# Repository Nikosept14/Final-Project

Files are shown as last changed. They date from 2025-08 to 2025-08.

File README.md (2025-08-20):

# 🤖 Humanoid Dancing Robot – 29 DOF Controller

This repository contains the source code and documentation for my undergraduate thesis:  
**"Rancang Bangun Sistem Kontroler 29-DOF pada Robot Penari Humanoid untuk Gerakan Tari yang Dinamis"**

---

## 📌 Project Description
This project focuses on the design and implementation of a **29 Degrees of Freedom (DOF) humanoid dancing robot**.  
The system utilizes an **ESP32 microcontroller** and **Dynamixel servomotors** to perform **dynamic dance movements**, following the guidelines of the **Indonesian Robot Contest (KRI) 2024**.  

The controller system is capable of:
- Coordinating **multi-DOF motion** for humanoid dance movements.
- Achieving flexibility and balance
- Executing pre-programmed dynamic dance sequences.

---

## 🛠️ Tech Stack
- **Hardware**: ESP32, Dynamixel Servomotors  
- **Software/Frameworks**: Arduino IDE / PlatformIO, C/C++  
- **Control Algorithm**: Multi-DOF Motion Control  
- **Reference**: KRI 2024 Dance Robot Guidelines

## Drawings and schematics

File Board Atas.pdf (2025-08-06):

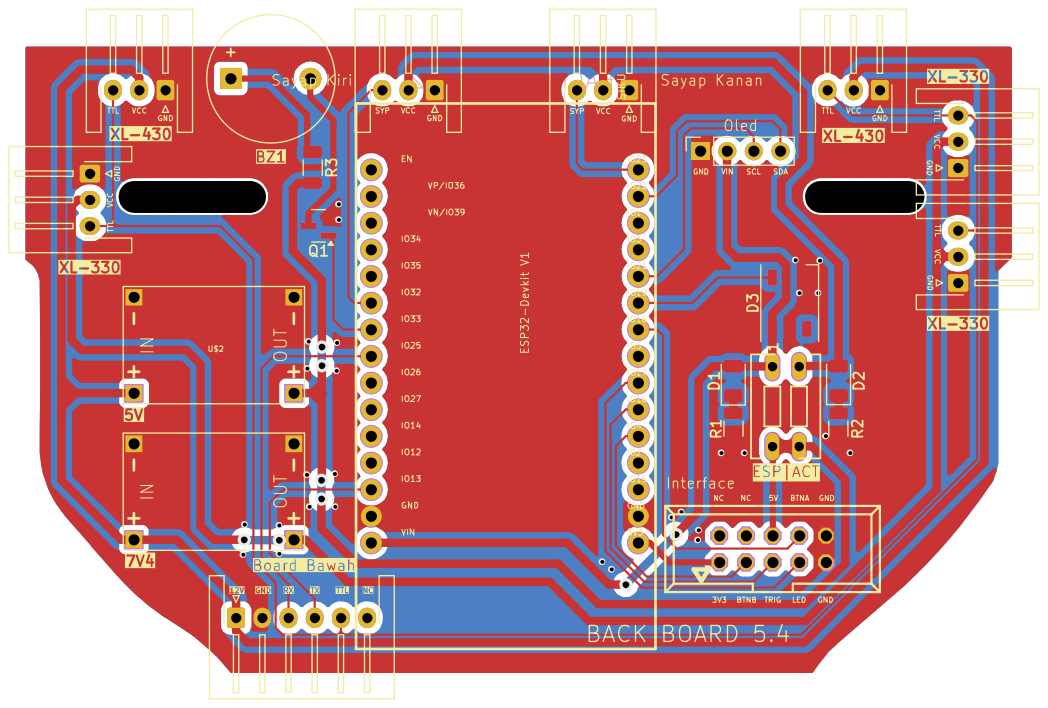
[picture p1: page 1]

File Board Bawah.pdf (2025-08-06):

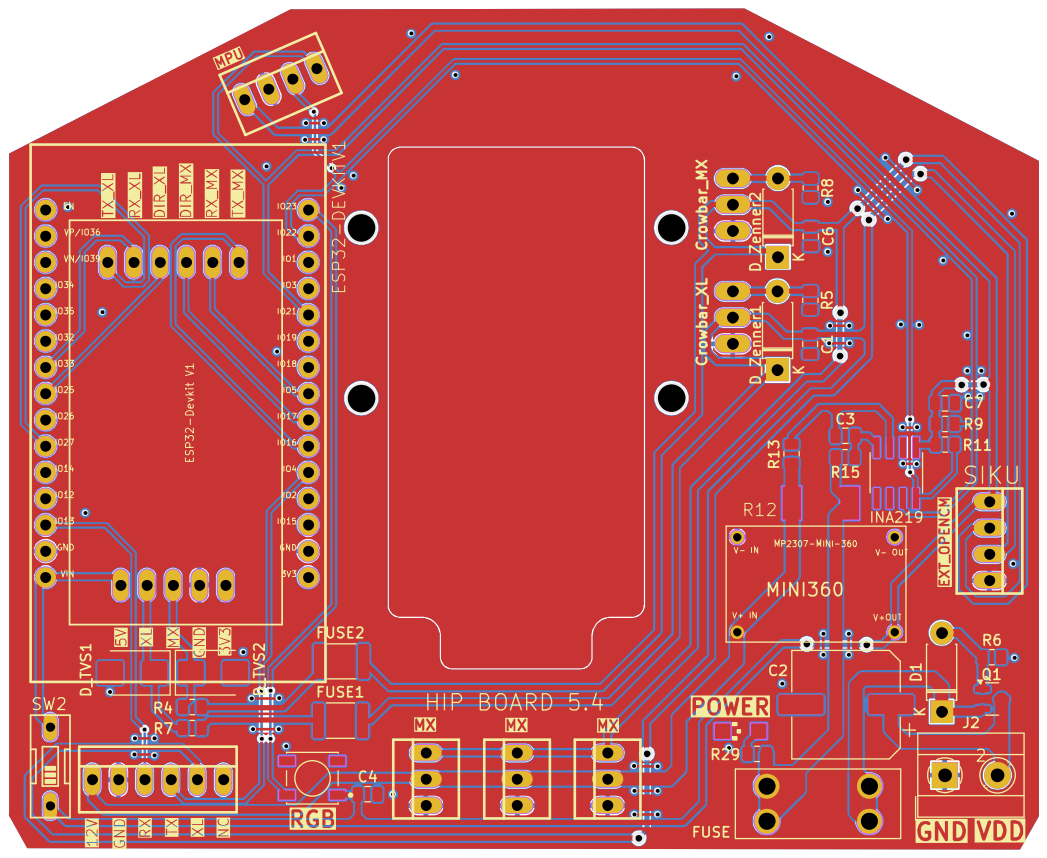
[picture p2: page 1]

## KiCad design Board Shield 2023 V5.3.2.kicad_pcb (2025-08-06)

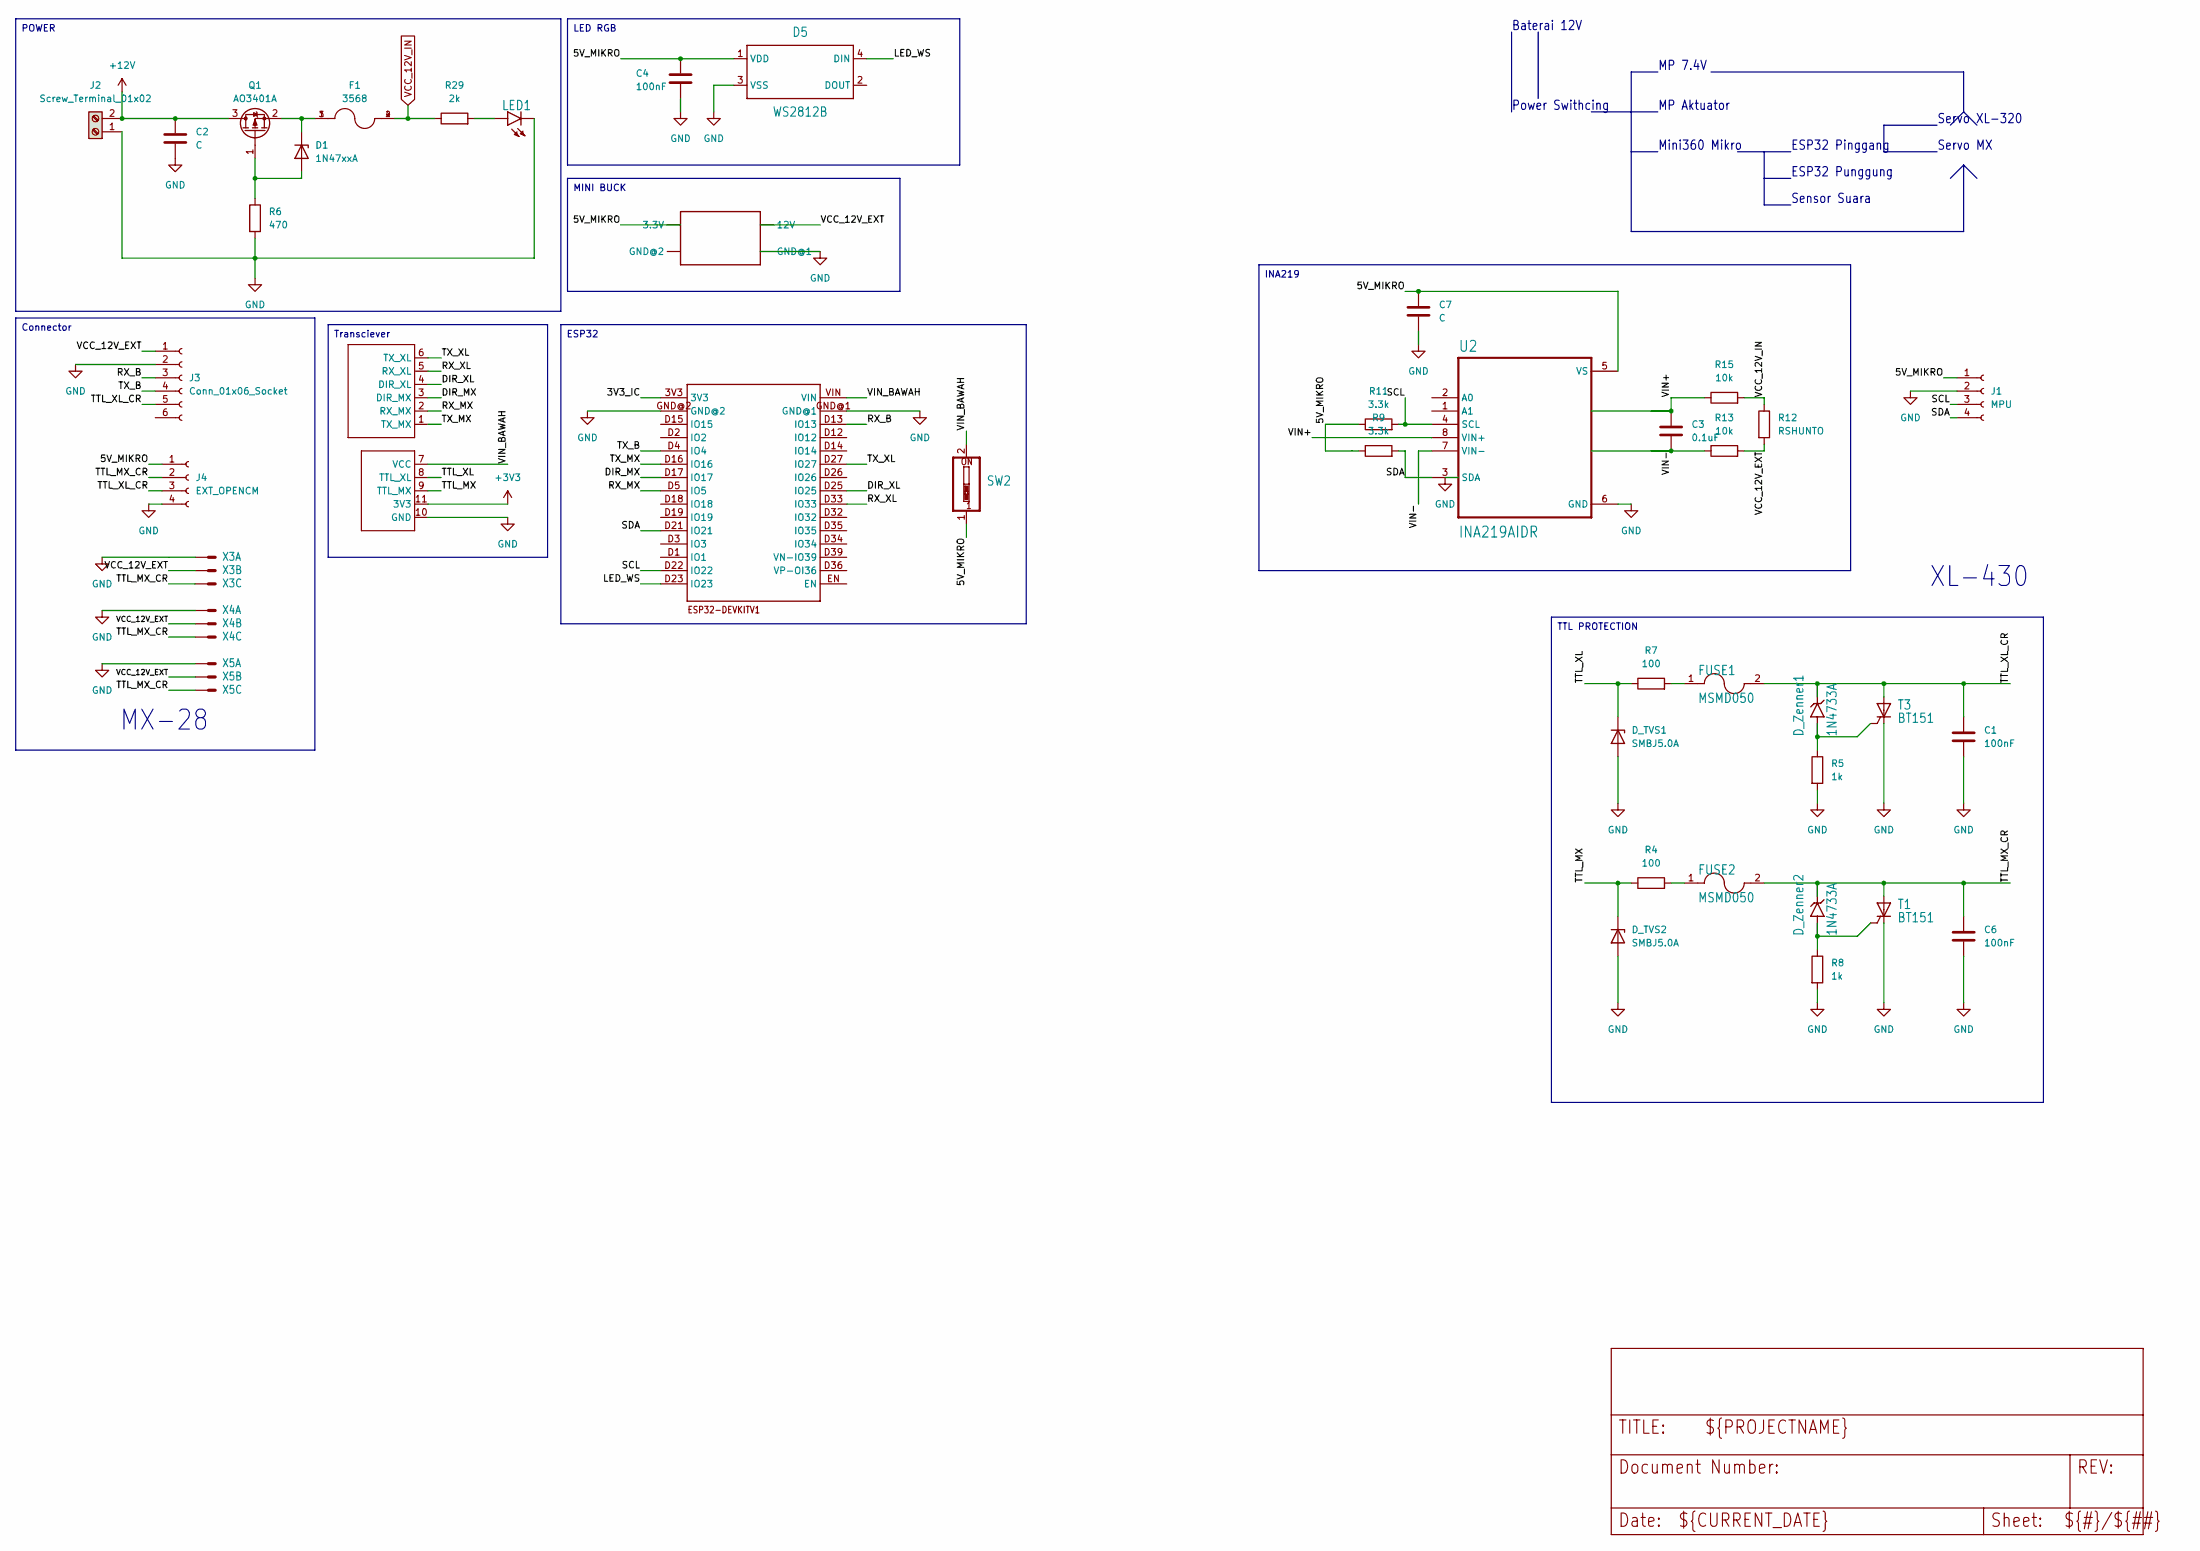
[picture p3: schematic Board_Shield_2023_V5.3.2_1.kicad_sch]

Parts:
C1, C4, C6: 100nF; C_0805_2012Metric
C2: C; CP_Elec_10x12.6
C3: 0.1uF; C_0805_2012Metric
C7: C; C_0805_2012Metric
D1: 1N47xxA; D_DO-41_SOD81_P7.62mm_Horizontal
D5: WS2812B; WS2812B_22900745
D_TVS1, D_TVS2: SMBJ5.0A; D_SMB
D_Zenner1, D_Zenner2: 1N4733A; D_DO-41_SOD81_P7.62mm_Horizontal
F1: 3568; FUSE_3568; PARTREV C
FUSE1, FUSE2: MSMD050; Fuse_1812_4532Metric
J1: MPU; 22-23-2041_165
J2: Screw_Terminal_01x02; TerminalBlock_MetzConnect_Type101_RT01602HBWC_1x02_P5.08mm_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
J3: Conn_01x06_Socket; 22-23-2061_165
J4: EXT_OPENCM; 22-23-2041_165
LED1: LEDCHIPLED_1206; CHIPLED_1206
MINI360: MP2307-MINI-360
Q1: AO3401A; SOT-23
R4, R7: 100; R_0805_2012Metric
R5, R8: 1k; R_0805_2012Metric
R6: 470; R_0805_2012Metric
R9, R11: 3.3k; R_0805_2012Metric
R12: RSHUNTO; R2512_334
R13, R15: 10k; R_0805_2012Metric
R29: 2k; R_0805_2012Metric
SW2: EDG-01_367
T1, T3: BT151; TO220CL
U2: INA219AIDR; SOIC127P599X175-8N
U$5: ESP32DEVKITV1; ESP32-DEVKITV1
U$6: TRANSCEIVER_2.0
X3, X4, X5: 22-23-2031

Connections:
+3V3: U$6.11 (3V3)
+12V: C2.1, J2.2, Q1.3 (D)
/Board Shield 2023 V5.3.2_1/3V3_IC: U$5.3V3
/Board Shield 2023 V5.3.2_1/5V_MIKRO: C4.1, C7.1, D5.1 (VDD), J1.1, J4.1, MINI360.V+OUT (3.3V), R9.1, R11.1, SW2.1, U2.5 (VS)
/Board Shield 2023 V5.3.2_1/DIR_MX: U$5.D17 (IO17), U$6.3 (DIR_MX)
/Board Shield 2023 V5.3.2_1/DIR_XL: U$5.D25 (IO25), U$6.4 (DIR_XL)
/Board Shield 2023 V5.3.2_1/LED_WS: D5.4 (DIN), U$5.D23 (IO23)
/Board Shield 2023 V5.3.2_1/RX_B: J3.3, U$5.D13 (IO13)
/Board Shield 2023 V5.3.2_1/RX_MX: U$5.D5 (IO5), U$6.2 (RX_MX)
/Board Shield 2023 V5.3.2_1/RX_XL: U$5.D33 (IO33), U$6.5 (RX_XL)
/Board Shield 2023 V5.3.2_1/SCL: J1.3, R11.2, U2.4 (SCL), U$5.D22 (IO22)
/Board Shield 2023 V5.3.2_1/SDA: J1.4, R9.2, U2.3 (SDA), U$5.D21 (IO21)
/Board Shield 2023 V5.3.2_1/TTL_MX: D_TVS2.1 (K), R4.1, U$6.9 (TTL_MX)
/Board Shield 2023 V5.3.2_1/TTL_MX_CR: C6.1, D_Zenner2.1 (K), FUSE2.2, J4.2, T1.A, X3.3 (S), X4.3 (S), X5.3 (S)
/Board Shield 2023 V5.3.2_1/TTL_XL: D_TVS1.1 (K), R7.1, U$6.8 (TTL_XL)
/Board Shield 2023 V5.3.2_1/TTL_XL_CR: C1.1, D_Zenner1.1 (K), FUSE1.2, J3.5, J4.3, T3.A
/Board Shield 2023 V5.3.2_1/TX_B: J3.4, U$5.D4 (IO4)
/Board Shield 2023 V5.3.2_1/TX_MX: U$5.D16 (IO16), U$6.1 (TX_MX)
/Board Shield 2023 V5.3.2_1/TX_XL: U$5.D27 (IO27), U$6.6 (TX_XL)
/Board Shield 2023 V5.3.2_1/VCC_12V_EXT: J3.1, MINI360.V+IN (12V), R12.2, R13.2, X3.2 (S), X4.2 (S), X5.2 (S)
/Board Shield 2023 V5.3.2_1/VIN+: C3.1, R15.1, U2.8 (VIN+)
/Board Shield 2023 V5.3.2_1/VIN-: C3.2, R13.1, U2.7 (VIN-)
/Board Shield 2023 V5.3.2_1/VIN_BAWAH: SW2.2, U$5.VIN, U$6.7 (VCC)
GND: C1.2, C2.2, C4.2, C6.2, C7.2, D5.3 (VSS), D_TVS1.2 (A), D_TVS2.2 (A), J1.2, J2.1, J3.2, J4.4, LED1.C, MINI360.GND_IN (GND@1), R5.2, R6.2, R8.2, T1.C, T3.C, U2.6 (GND), U$5.GND@1, U$5.GND@2, U$6.10 (GND), X3.1 (S), X4.1 (S), X5.1 (S)
unnamed: D1.2 (A), Q1.1 (G), R6.1
unnamed: D1.1 (K), F1.1, F1.3, Q1.2 (S)
unnamed: D_Zenner1.2 (A), R5.1, T3.G
unnamed: D_Zenner2.2 (A), R8.1, T1.G
unnamed: FUSE1.1, R7.2
unnamed: FUSE2.1, R4.2
unnamed: LED1.A, R29.2
VCC_12V_IN: F1.2, F1.4, R12.1, R15.2, R29.1

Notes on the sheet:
ESP32
INA219
MINI BUCK
Connector
TTL PROTECTION
POWER
Transciever
LED RGB
MX-28
Servo MX
Sensor Suara
Mini360 Mikro
ESP32 Pinggang
MP Aktuator
Baterai 12V
Power Swithcing
ESP32 Punggung
XL-430
MP 7.4V
Servo XL-320

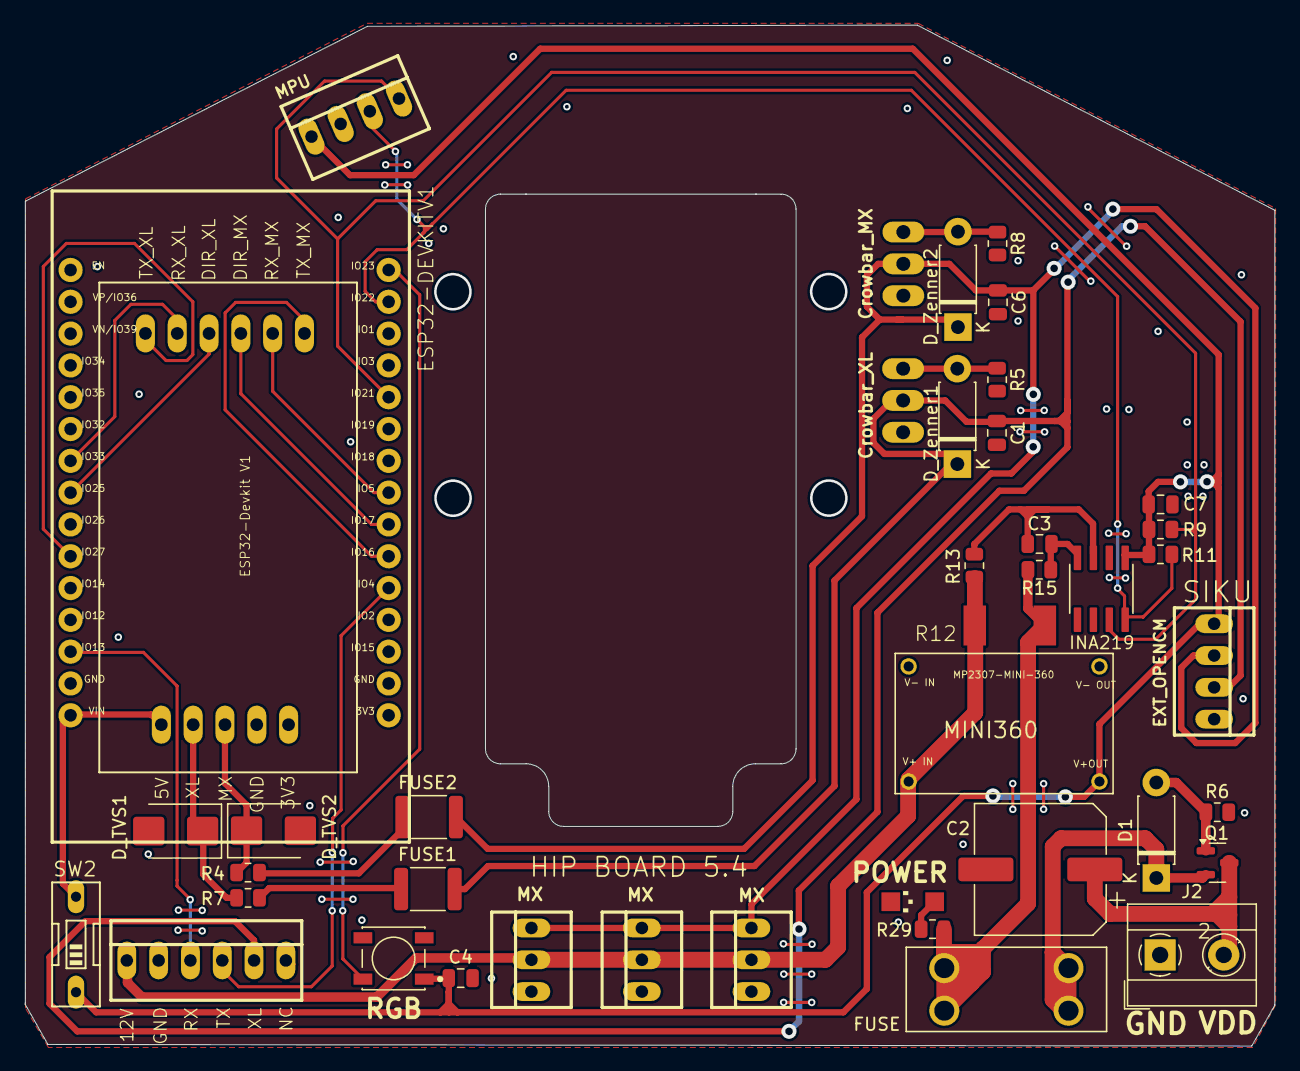
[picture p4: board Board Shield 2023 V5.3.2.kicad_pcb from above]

Board: 2 copper layers, 99.8 x 81.5 mm, 42 parts (0 on the bottom side), 30 nets.

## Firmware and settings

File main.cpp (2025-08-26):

#include "main.h"

int last_time;
unsigned long index_time = 0;
Sound* sound = nullptr;

// bisma faq

void on_startup_sequence() {
    DEBUG_PRINTF("[Main-Micro] Communication Start Up, Expecting a ping from Sub program\n");
    LED_main.setFlicker(CRGB::Red, 100, 100);
    int timeout = 2000;
    for (int i = timeout; i > 0; i--) {
        digitalWrite(LED_BUILTIN, !digitalRead(LED_BUILTIN));
        if (Serial2.available()) {
            // if (Serial2.read() != 0xFD && Serial2.read() != 0x00 && Serial2.read()) continue;
            if (Serial2.read() != 0xFD) continue;
            if (Serial2.read() != 0x00) continue;
            DEBUG_PRINTF("[POST] RECV Data From:%d ", Serial2.read());
            int len = Serial2.read();
            if (Serial2.read() == PING) {
                LED_main.turnOn(CRGB::Yellow);
                DEBUG_PRINTF("[Main-Micro] Serial Comunnication Estabilished Success\n");
                DEBUG_PRINTF("[Main-Micro] Sending Ping Feedback\n");
                byte ping_data[1] = {RESPONSE_PING};
                serial_send(ping_data, sizeof(ping_data));
                delay(100);
                for (int i = timeout; i > 0; i--) {
                    if (Serial2.available()) {
                        // if (Serial2.read() != 0xFD && Serial2.read() != 0x00 && Serial2.read()) continue;
                        if (Serial2.read() != 0xFD) continue;
                        if (Serial2.read() != 0x00) continue;
                        DEBUG_PRINTF("[POST] RECV Data From:%d ", Serial2.read());
                        int len = Serial2.read();
                        if (Serial2.read() == SET_IDENTITY) {
                            DEBUG_PRINTF("[Main-Micro] Getting Identity\n");
                            EEPROM.writeByte(ADDR_IDENTITY, Serial2.read());
                            EEPROM.writeByte(ADDR_ASSIGNED_PARTNER, Serial2.read());
                            LED_main.turnOn(CRGB::Green);
                            EEPROM.commit();
                            DEBUG_PRINTF("[Main-Micro] Identity Set to %s[%d]\n", mac_names[EEPROM.readByte(ADDR_IDENTITY)], EEPROM.readByte(ADDR_IDENTITY));
                            DEBUG_PRINTF("[Main-Micro] Partner Set to %s[%d]\n", mac_names[EEPROM.readByte(ADDR_ASSIGNED_PARTNER)], EEPROM.readByte(ADDR_ASSIGNED_PARTNER));
                            i = 0;
                        }
                        break;
                    }
                }
            }
            return;
        }
        if (i <= 1) {
            DEBUG_PRINTF("[Main-Micro] Startup Timeout no [SUB-MICRO] PING received\n");
            DEBUG_PRINTF("[Main-Micro] Identity Set to default value [2][3]\n");
            EEPROM.writeByte(ADDR_IDENTITY, 2);
            EEPROM.writeByte(ADDR_ASSIGNED_PARTNER, 3);
            EEPROM.commit();

            // LED_main.turnOn(CRGB::Red);
            LED_main.setFlicker(CRGB::Red, 250, 250);
            digitalWrite(SOUND, HIGH);
            delay(500);
            digitalWrite(SOUND, LOW);
            return;
        }
        delay(1);
    }
}

void error_feedback(uint8_t error_value, bool sound) {
    digitalWrite(SOUND, LOW);
    DEBUG_PRINTF("[Main-Micro] Error: %s\n", error_code_to_name((ERROR)error_value));
    if (error_value == ESP_NOW_ERR) {
        LED_main.setFlicker(CRGB::Red, 500, 100);
        for (int i = 0; i < 10; i++) {
            digitalWrite(SOUND, !digitalRead(SOUND));
            delay(100);
        }
    } else if (error_value == SERIAL_ERR) {
        LED_main.setFlicker(CRGB::Red, 100, 50);
        digitalWrite(SOUND, HIGH);
        delay(500);
        digitalWrite(SOUND, LOW);
    } else if (error_value == MOTION_ERR) {
        LED_main.setFlicker(CRGB::Blue, 100, 50);
        for (int i = 0; i < 4; i++) {
            digitalWrite(SOUND, !digitalRead(SOUND));
            delay(100);
        }
    } else if (error_value == SERVO_ERR) {
        LED_main.setFlicker(CRGB::Black, 100, 50);
        for (int i = 0; i < 6; i++) {
            digitalWrite(SOUND, !digitalRead(SOUND));
            delay(100);
        }
    } else if (error_value == LOW_BATTERY) {
        LED_main.setFlicker(CRGB::Black, 500, 100);
        for (int i = 0; i < 8; i++) {
            digitalWrite(SOUND, !digitalRead(SOUND));
            delay(100);
        }
    }
    digitalWrite(SOUND, LOW);
    LED_main.turnOn(CRGB::Red);
}

void additional_loop(void* pvParameters) {
    DEBUG_PRINTF("[Main-Micro] addtitional loop begin\n");
    while (true) {
        // Button Event
        mode_a.read();
        mode_b.read();
        trig.read();
        button.read();

        // LED Event
        LED_main.loop();
        LED_interface.loop();
        vTaskDelay(1 / portTICK_PERIOD_MS);
    }
}

void setup() {
    EEPROM.begin(EEPROM_SIZE);

    Serial.begin(115200);
    Serial2.begin(115200, SERIAL_8N1, UART_2_RX, UART_2_TX);
    pinMode(LED_BUILTIN, OUTPUT);
    pinMode(SOUND, OUTPUT);
    digitalWrite(LED_BUILTIN, LOW);

    // EEPROM.writeBool(ADDR_ESP_NOW_ACTIVE, false);
    // EEPROM.commit();
    /* Initialize ESP-NOW */
    // if (EEPROM.readBool(ADDR_ESP_NOW_ACTIVE)) {
    //     esp_err_t result = initESPNow(ESP_MAC_INDEX, LED_BUILTIN);
    //     DEBUG_PRINTF("[ESP-NOW] Init as %s, err: %s\n", mac_names[ESP_MAC_INDEX], esp_err_to_name(result));
    //     digitalWrite(LED_BUILTIN, HIGH);

    // } else {
    //     DEBUG_PRINTF("[ESP-NOW] Disabled\n");
    // }

    DEBUG_PRINTF("[MAIN-Micro] FW Version: %s\n Last Upload: %s, %s\n", FIRMWARE_VERSION, __DATE__, __TIME__);
    DEBUG_PRINTF("COMMIT ID : %s, ", COMMIT_ID);
    DEBUG_PRINTF("COMMIT DATE : %s, ", COMMIT_DATE);
    DEBUG_PRINTF("BRANCH : %s, ", COMMIT_BRANCH);
    DEBUG_PRINTF("UPLOADER : %s\n", COMMIT_UPLOADER);

    /* Additonal Features (Button & LED)*/
    initButton();
    FastLED.addLeds<WS2812B, LED_PCB, GRB>(leds, 1);
    FastLED.addLeds<WS2812B, LED_INTERFACE, GRB>(leds2, 1);

    /* Startup Sequence */
    /* Initialize Pin Servo Tambahan */
    Mata.init(PIN_MATA);
    Tangan_Kanan.init(PIN_TANGAN_KANAN);
    Tangan_Kiri.init(PIN_TANGAN_KIRI);
    Mata.write(90);

    /* Startup Sequence with Sub program*/
    on_startup_sequence();
    digitalWrite(LED_BUILTIN, LOW);

    DEBUG_PRINTF("[Main-Micro] Startup Sequence Done\n");
    DEBUG_PRINTF("[Main-Micro] Identity: %s[%d]\n", mac_names[EEPROM.readByte(ADDR_IDENTITY)], EEPROM.readByte(ADDR_IDENTITY));
    DEBUG_PRINTF("[Main-Micro] Partner: %s[%d]\n", mac_names[EEPROM.readByte(ADDR_ASSIGNED_PARTNER)], EEPROM.readByte(ADDR_ASSIGNED_PARTNER));
    xTaskCreate(additional_loop, "additional_loop", 8192, NULL, 1, NULL);
    if (EEPROM.readByte(ADDR_USE_BT_SOUND) && EEPROM.readByte(ADDR_IDENTITY) == 2) {
        DEBUG_PRINTF("[Main-Micro] Use BT Sound\n");
        sound = new Sound("Vi-Rose ITS", false);
    } else {
        DEBUG_PRINTF("[Main-Micro] No BT Sound\n");
    }

    /* Initialize Sound Sensor */
    if (sound != nullptr) {
        // #if (SOUND_BT)
        for (int i = 0; i < 6; i++) {
            digitalWrite(LED_BUILTIN, !digitalRead(LED_BUILTIN));
            delay(50);
        }
        sound->start(&LED_main);
        // #else
        // Kipas.init(PIN_KIPAS);
        // #endif
    }

    EEPROM.readByte(ADDR_IDENTITY) == 2 ? LED_main.turnOn(CRGB::DeepPink) : LED_main.turnOn(CRGB::Cyan);
    delay(100);

    // if replay previous motion
    if (!EEPROM.readBool(PLAY_MOTION_FINISHED)) {
        esp_info.index = EEPROM.readInt(ADDR_LAST_INDEX);
    }
    DEBUG_PRINTF("[MAIN-MIRCRO] Ready\n");
    // LED_main.turnOff();
}

void loop() {
    // Read Button
    // mode_a.read();
    // mode_b.read();
    // trig.read();
    // button.read();

    // Additional Servo
    Tangan_Kanan.loop();
    Tangan_Kiri.loop();
    Mata.loop();

    if (sound != nullptr)
        soundStatus();
    // #else
    //     // Kipas.loop();
    // #endif

    // Check serial communication
    if (Serial2.available()) serial_recv(on_serial_recv_cb);

    // Check if the motion is done and stop the motion
    if (esp_info.mx_status && esp_info.xl_status && esp_info.index == EEPROM.readByte(ADDR_MOTION_MOVIE_LENGTH)) {
        esp_info.mx_status = false;
        esp_info.xl_status = false;
        esp_info.index = 0;
        EEPROM.writeInt(ADDR_LAST_INDEX, esp_info.index);
        EEPROM.writeBool(PLAY_MOTION_FINISHED, true);
        EEPROM.commit();
    }

    // Check if motion is done and play the next motion
    if (esp_info.mx_status && esp_info.xl_status && esp_info.index < EEPROM.readByte(ADDR_MOTION_MOVIE_LENGTH) && esp_info.index > 1) {
        esp_info.mx_status = false;
        esp_info.xl_status = false;
        esp_info.index++;
        EEPROM.writeInt(ADDR_LAST_INDEX, esp_info.index);
        EEPROM.commit();
        byte data_index[9];

        DEBUG_PRINTF("[POST] LAST INDEX: %d\n", esp_info.index);

        if (esp_info.sync_play) {
            data_index[0] = POST_COMUNICATION_CHAIN;
            data_index[1] = EEPROM.readByte(ADDR_ASSIGNED_PARTNER);
            data_index[2] = -1;
            data_index[3] = POST_MOTION_PLAY;
            mempcpy(data_index + 4, &esp_info.index, sizeof(esp_info.index));
            // if (EEPROM.readBool(ADDR_ESP_NOW_ACTIVE))
            //     esp_now_send(mac_addresses[mac_index_target], data_index, sizeof(data_index));
            // else
            serial_send(data_index, sizeof(data_index));
            LED_main.turnOn(CRGB::DeepPink);
            esp_info.sync_play = false;
        }
        memset(data_index, 0, sizeof(data_index));
        data_index[0] = POST_MOTION_PLAY;
        memcpy(data_index + 1, &esp_info.index, sizeof(esp_info.index));
        memcpy(data_index + 5, &esp_info.index, sizeof(esp_info.index));
        // if (EEPROM.readBool(ADDR_ESP_NOW_ACTIVE))
        //     esp_now_send(mac_addresses[mac_index_target], data_index, sizeof(data_index));
        // else
        serial_send(data_index, sizeof(data_index));
        DEBUG_PRINTF("[POST] Play Motion %d\n", esp_info.index);
    }
}

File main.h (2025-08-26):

#pragma once

#include <Arduino.h>
#include <EEPROM.h>
#include <EasyButton.h>
#include <MG90.h>
#include <SPIFFS.h>
#include <Ticker.h>
#include <VIROSE_Lib.h>
#include <display.h>
#include <led.h>

#include "utility/debug.h"
#include "virose_com.h"
/*   ┌——————————————————————————————————————————————————————————————————————————————————————————————┐
     │                                        Definitions                                           │
     └——————————————————————————————————————————————————————————————————————————————————————————————┘     */

/* Pin Kumunikasi */
#define UART_1_RX 33
#define UART_1_TX 27
#define I2C_SDA 22
#define I2C_SCL 21
#define PIN_TANGAN_KANAN 100
#define PIN_TANGAN_KIRI 101

/*  */
#define UART_2_RX 13
#define UART_2_TX 25
#define PIN_BUTTON1 18
#define PIN_BUTTON2 4
#define PIN_TRIG 16
#define PIN_MATA 32
#define PIN_KIPAS 23
#define LED_INTERFACE 17
#define LED_PCB 19
#define SOUND 33

// /* Pin Kumunikasi LAMA*/
// #define UART_2_RX 25
// #define UART_2_TX 13
// // // /*  */
// #define PIN_BUTTON1 18
// #define PIN_BUTTON2 17
// #define PIN_TRIG 16
// #define PIN_MATA 27
// #define PIN_KIPAS 33
// #define LED_PCB 19
// #define LED_INTERFACE 4
// #define SOUND 34

/* ADDRESS EEPROM */
#define EEPROM_SIZE 128

/* ESP ADDRESS */
#define ADDR_ESP_NOW_ACTIVE 0

/* lAST INDEX */
#define ADDR_LAST_INDEX 4

#define PLAY_MOTION_FINISHED 8

#define FIRMWARE_VERSION "5.7.3"

/*   ┌——————————————————————————————————————————————————————————————————————————————————————————————┐
     │                                    Enum and Structure                                        │
     └——————————————————————————————————————————————————————————————————————————————————————————————┘     */

typedef struct esp_info {
    IPAddress mac;   // IP Address dari ESP32
    int index;       // Index Motion
    bool sound;      // Status Sound
    bool xl_status;  //  status XL-320
    bool mx_status;  //  status MX-28
    bool mata_status;
    bool sync_play;
    int index_sent;
} esp_info_t;

/*   ┌——————————————————————————————————————————————————————————————————————————————————————————————┐
     │                                     External Variables                                       │
     └——————————————————————————————————————————————————————————————————————————————————————————————┘     */

extern esp_info_t esp_info;  // Robot Info Struct
extern EasyButton mode_a;    // Button untuk Mode A
extern EasyButton mode_b;    // Button untuk Mode B
extern EasyButton trig;      // Button untuk Trigger
extern EasyButton button;    // Button untuk Interface
extern LedBender LED_main;
extern LedBender LED_interface;
extern CRGB leds[1];
extern CRGB leds2[1];
extern MG90 Mata;
extern MG90 Kipas;
extern MG90 Tangan_Kanan;
extern MG90 Tangan_Kiri;
extern Sound* sound;
extern int interval_comm;
extern int mac_index_target;
extern int mac_index_partner;
extern uint8_t IDENTITY;

/*   ┌——————————————————————————————————————————————————————————————————————————————————————————————┐
     │                                      Functions Prototype                                     │
     └——————————————————————————————————————————————————————————————————————————————————————————————┘     */

/**
 * @brief Aktivasi dan cek apakah untuk sound sensor sudah aman
 */
void soundStatus();

/**
 * @brief Callback serial event
 */
void serial_event();

/**
 * @brief Fungsi untuk init button
 */
void initButton();

/**
 * @brief Fungsi untuk mengirimkan data ke subcontroller
 * @param data data yang akan dikirimkan
 * @param len panjang data
 * @param mac_index index dari MAC Address
 */
void processing_command(uint8_t* data, int len, int mac_index = -1);

/**
 * @brief Callback untuk Mode Button A ketika dipencet
 */
void Button_Mode_A_Callback();

/**
 * @brief Callback untuk Mode Button A ketika ditekan lama
 */
void Button_Mode_A_Hold_Callback();

/**
 * @brief Callback untuk Mode Button A ketika dipencet 2 kali
 */
void Button_Mode_A_2_Sequence_Callback();

/**
 * @brief Callback untuk Mode Button A ketika dipencet 3 kali
 */
void Button_Mode_A_3_Sequence_Callback();

/**
 * @brief Callback untuk Mode Button B ketika dipencet
 */
void Button_Mode_B_Callback();

/**
 * @brief Callback untuk Mode Button B ketika ditekan lama
 */
void Button_Mode_B_Hold_Callback();

/**
 * @brief Callback untuk Mode Button B ketika dipencet 2 kali
 */
void Button_Mode_B_2_Sequence_Callback();

/**
 * @brief Callback untuk Mode Button B ketika dipencet 3 kali
 */
void Button_Mode_B_3_Sequence_Callback();

/**
 * @brief Callback untuk Trig Button ketika dipencet
 */
void Button_Trig_Callback();

/**
 * @brief Callback untuk Trig Button ketika ditekan lama
 */
void Button_Trig_Hold_Callback();

/**
 * @brief Callback untuk Trig Button ketika ditekan 2 kali
 */
void Button_Trig_2_Sequence_Callback();

// void initTaskBattery();

void error_feedback(uint8_t error_value, bool sound);
